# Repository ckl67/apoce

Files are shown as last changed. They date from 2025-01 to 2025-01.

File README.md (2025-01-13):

/* =================================================================
	Pilote Arduino pour optimiser la gestion de consommation électrique
    Christian Klugesherz
    Date : 12 janvier 2025 --> Nouvelle approche avec double fonction de boutons
	
    Le schéma de la carte se trouve dans le répertoire Board
    La simulation se trouve sur
    https://www.tinkercad.com/things/i7El4JjrINq-pilote-contacteur
    L'Arduino Nano est basée sur l'ATmega328

    Code sous github : https://github.com/ckl67/apoce

	ATTENTION:
	===========
		Il est impératif de configurer la partie "Configuration" ci-dessous !
		
    Principe
    =========
    Entrée :
      * Signal Jour/Nuit - J/N
      * Signal Soleil - SOL
    Sortie :
      * Signal pour piloter contacteur Chauffe Eau 1 - CA1
      * Signal pour piloter contacteur Chauffe Eau 2 - CA2
      * Signal pour piloter contacteur Chargement Voiture - CV
	Bouton :
	  * BoutonJN --> Permet aussi de forcer CA1
	  * BoutonSOL--> Permet aussi de forcer CA2
	  * BoutonAUTO--> Permet aussi de forcer V
    Modes :
	  Dans le principe, un changement de mode, va re-initialiser le compteur d'armement

Les Modes disponibles :

	  -------------------------------------------
      * Mode JN : Jour-Nuit --> Led : Bleue Allumée
      --------------------------------------------
	 Si ModeArm = 0
        Si signal J/N = 1
            Basculement entre pilotage "CA1" puis "CA2" 
	 Si ModeArm = 1 
        Si signal J/N = 1
            Basculement entre pilotage "CA1" puis "CA2" puis "CV"  
		
    Si signal J/N = 0
          Pas de pilotage
		  
      -------------------------------------------
      * Mode SOL : Soleil --> Led Orange Allumée
      --------------------------------------------
    Si ModeArm = 0
        Si signal SOL = 1
          Basculement entre pilotage "CA1" puis "CA2"
	  Si ModeArm = 1 
        Si signal SOL = 1
          Basculement entre pilotage "CA1" puis "CA2" puis "CV"
    Si SOL = 0
          Pas de pilotage

      -------------------------------------------
      * Mode Auto : Jour-Nuit + Soleil --> Led Rouge Allumée
      --------------------------------------------
 	 Si ModeArm = 0
        Si signal SOL = 1 || Signal J/N = 1
          Basculement entre pilotage "CA1" puis "CA2"
	Si ModeArm = 1 
        Si signal SOL = 1 || Signal J/N = 1
          Basculement entre pilotage "CA1" puis "CA2" puis "CV"

	Si signal J/N = 0 ET SOL = 0
          Pas de pilotage
	
      -------------------------------------------
      * Bouton Armement pressé 1X --> Led Blanche Clignotante
      --------------------------------------------
		Quelque soit le mode : ModeArm = 1
			--> Nous intégrons la voiture dans le cycle 
			--> Nous utilisons la variable : SwitchContactSelection
			définie : ArmDuration
 
      -------------------------------------------
      * Bouton Armement pressé 2X --> Led Blanche Clignotante Rapide
      --------------------------------------------
			Quelque soit le mode : ModeArm = 2
				Sans courant de nuit, ni Soleil  : Basculement entre pilotage "CA1" puis "CA2" puis "V" sur une durée 
					définie : ArmDuration

      -------------------------------------------
      * Bouton Forcage JN=CA1 ou SOL=CA2 ou AUTO=V 
      -------------------------------------------
      Un premier appui sur le bouton va 
        * Positionner le forcage, 
      un deuxième va 
        * Positionner le mode

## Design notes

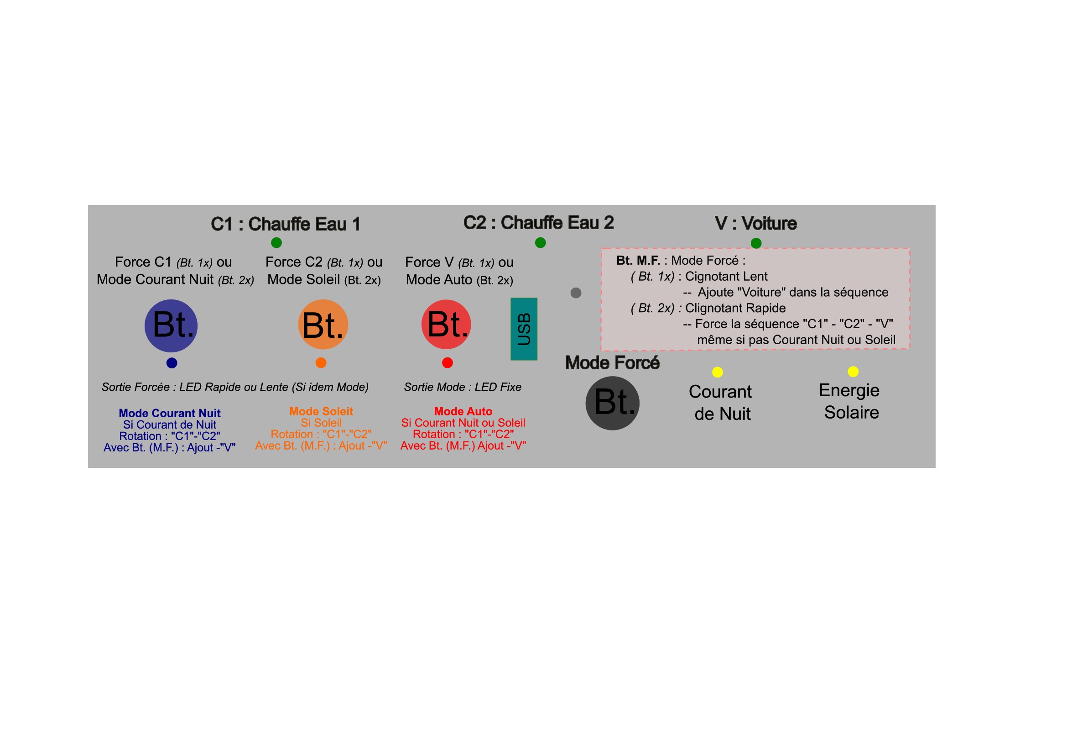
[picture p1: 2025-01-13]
Etiquette/Face.jpg

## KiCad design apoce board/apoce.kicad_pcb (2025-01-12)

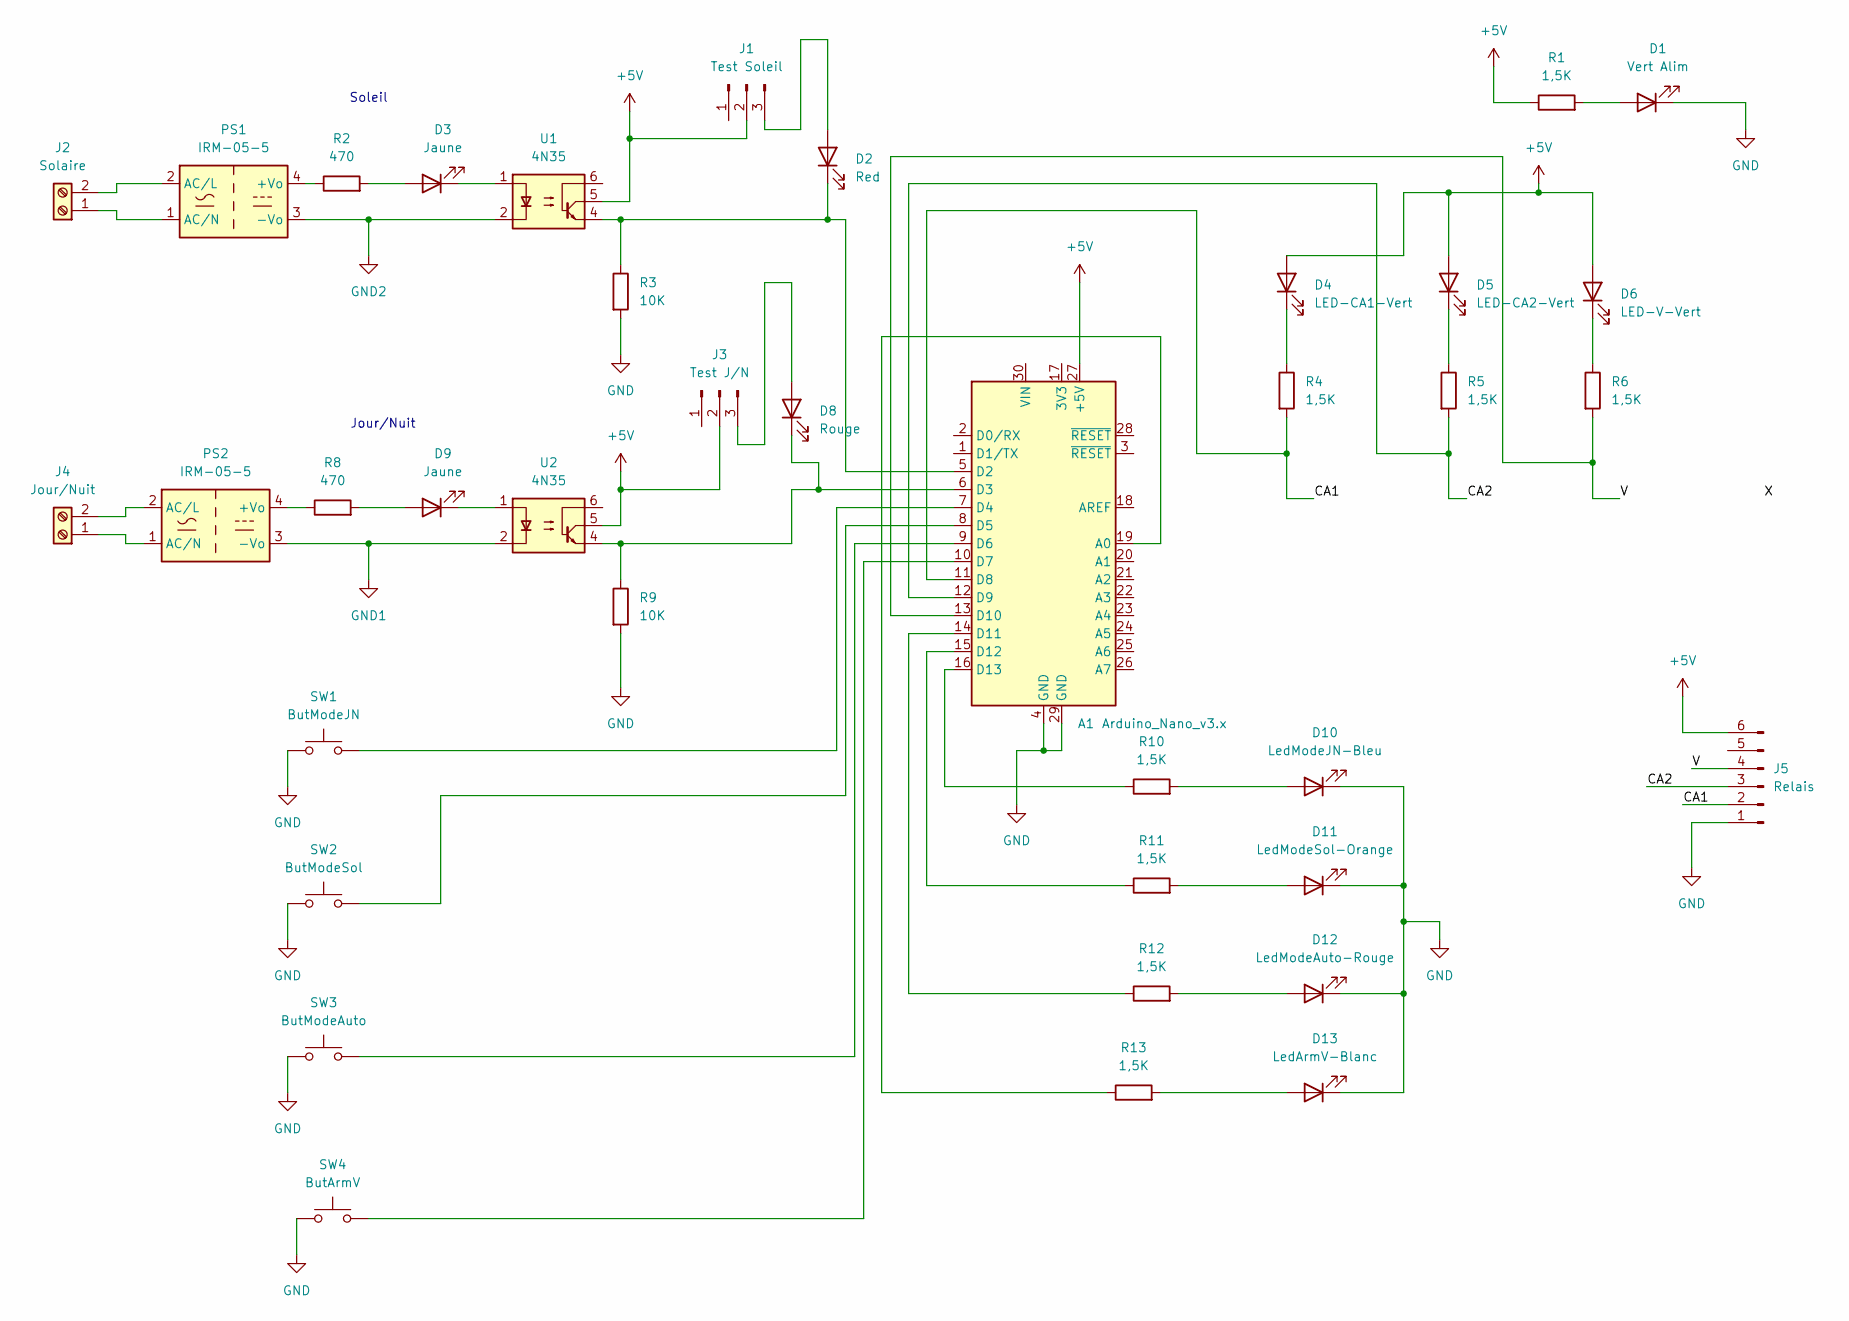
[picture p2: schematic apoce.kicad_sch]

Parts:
A1: Arduino_Nano_v3.x; Arduino_Nano
D1: Vert Alim; LED_D5.0mm
D2: Red; LED_D5.0mm
D3, D9: Jaune; LED_D5.0mm
D4: LED-CA1-Vert; LED_D5.0mm
D5: LED-CA2-Vert; LED_D5.0mm
D6: LED-V-Vert; LED_D5.0mm
D8: Rouge; LED_D5.0mm
D10: LedModeJN-Bleu; LED_D5.0mm
D11: LedModeSol-Orange; LED_D5.0mm
D12: LedModeAuto-Rouge; LED_D5.0mm
D13: LedArmV-Blanc; LED_D5.0mm
J1: Test Soleil; TerminalBlock_Xinya_XY308-2.54-3P_1x03_P2.54mm_Horizontal
J2: Solaire; TerminalBlock_Phoenix_MKDS-1,5-2-5.08_1x02_P5.08mm_Horizont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
J3: Test J/N; TerminalBlock_Xinya_XY308-2.54-3P_1x03_P2.54mm_Horizontal
J4: Jour/Nuit; TerminalBlock_bornier-2_P5.08mm
J5: Relais; TerminalBlock_Xinya_XY308-2.54-6P_1x06_P2.54mm_Horizontal
PS1, PS2: IRM-05-5; Converter_ACDC_MeanWell_IRM-05-xx_THT
R1, R4, R5, R6, R10, R11, R12, R13: 1,5K; R_Axial_DIN0207_L6.3mm_D2.5mm_P10.16mm_Horizontal
R2, R8: 470; R_Axial_DIN0207_L6.3mm_D2.5mm_P10.16mm_Horizontal
R3, R9: 10K; R_Axial_DIN0207_L6.3mm_D2.5mm_P10.16mm_Horizontal
SW1: ButModeJN; TerminalBlock_Phoenix_MKDS-1,5-2-5.08_1x02_P5.08mm_Horizont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
SW2: ButModeSol; TerminalBlock_Phoenix_MKDS-1,5-2-5.08_1x02_P5.08mm_Horizont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
SW3: ButModeAuto; TerminalBlock_Phoenix_MKDS-1,5-2-5.08_1x02_P5.08mm_Horizont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
SW4: ButArmV; TerminalBlock_Phoenix_MKDS-1,5-2-5.08_1x02_P5.08mm_Horizont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
U1, U2: 4N35; DIP-6_W7.62mm_LongPads

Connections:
+5V: A1.27 (+5V), D4.2 (A), D5.2 (A), D6.2 (A), J1.2, J3.2, J5.6, R1.1, U1.5, U2.5
/CA1: A1.11 (D8), J5.2, R4.2
/CA2: A1.12 (D9), J5.3, R5.2
/V: A1.13 (D10), J5.4, R6.2
GND: A1.4 (GND), A1.29 (GND), D1.1 (K), D10.1 (K), D11.1 (K), D12.1 (K), D13.1 (K), J5.1, R3.2, R9.2, SW1.1, SW2.1, SW3.1, SW4.1
GND1: PS2.3 (-Vo), U2.2
GND2: PS1.3 (-Vo), U1.2
unnamed: A1.19 (A0), R13.1
unnamed: A1.5 (D2), D2.1 (K), R3.1, U1.4
unnamed: A1.6 (D3), D8.1 (K), R9.1, U2.4
unnamed: A1.7 (D4), SW1.2
unnamed: A1.8 (D5), SW2.2
unnamed: A1.9 (D6), SW3.2
unnamed: A1.10 (D7), SW4.2
unnamed: A1.14 (D11), R12.1
unnamed: A1.15 (D12), R11.1
unnamed: A1.16 (D13), R10.1
unnamed: D1.2 (A), R1.2
unnamed: D2.2 (A), J1.3
unnamed: D3.2 (A), R2.2
unnamed: D3.1 (K), U1.1
unnamed: D4.1 (K), R4.1
unnamed: D5.1 (K), R5.1
unnamed: D6.1 (K), R6.1
unnamed: D8.2 (A), J3.3
unnamed: D9.2 (A), R8.2
unnamed: D9.1 (K), U2.1
unnamed: D10.2 (A), R10.2
unnamed: D11.2 (A), R11.2
unnamed: D12.2 (A), R12.2
unnamed: D13.2 (A), R13.2
unnamed: J2.1, PS1.1 (AC/N)
unnamed: J2.2, PS1.2 (AC/L)
unnamed: J4.1, PS2.1 (AC/N)
unnamed: J4.2, PS2.2 (AC/L)
unnamed: PS1.4 (+Vo), R2.1
unnamed: PS2.4 (+Vo), R8.1

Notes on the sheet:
Jour/Nuit
Soleil

Board: 2 copper layers, 38 parts (0 on the bottom side), 37 nets, no tracks yet.

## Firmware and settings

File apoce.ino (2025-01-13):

/* =================================================================
	Pilote Arduino pour optimiser la gestion de consommation électrique
    Christian Klugesherz
    Date : 12 janvier 2025 --> Nouvelle approche avec double fonction de boutons
	
    Le schéma de la carte se trouve dans le répertoire Board
    La simulation se trouve sur
    https://www.tinkercad.com/things/i7El4JjrINq-pilote-contacteur
    L'Arduino Nano est basée sur l'ATmega328

    Code sous github : https://github.com/ckl67/apoce

	ATTENTION:
	===========
		Il est impératif de configurer la partie "Configuration" ci-dessous !
		
    Principe
    =========
    Entrée :
      * Signal Jour/Nuit - J/N
      * Signal Soleil - SOL
    Sortie :
      * Signal pour piloter contacteur Chauffe Eau 1 - CA1
      * Signal pour piloter contacteur Chauffe Eau 2 - CA2
      * Signal pour piloter contacteur Chargement Voiture - CV
	Bouton :
	  * BoutonJN --> Permet aussi de forcer CA1
	  * BoutonSOL--> Permet aussi de forcer CA2
	  * BoutonAUTO--> Permet aussi de forcer V
    Modes :
	  Dans le principe, un changement de mode, va re-initialiser le compteur d'armement

Les Modes disponibles :

	  -------------------------------------------
      * Mode JN : Jour-Nuit --> Led : Bleue Allumée
      --------------------------------------------
	 Si ModeArm = 0
        Si signal J/N = 1
            Basculement entre pilotage "CA1" puis "CA2" 
	 Si ModeArm = 1 
        Si signal J/N = 1
            Basculement entre pilotage "CA1" puis "CA2" puis "CV"  
		
    Si signal J/N = 0
          Pas de pilotage
		  
      -------------------------------------------
      * Mode SOL : Soleil --> Led Orange Allumée
      --------------------------------------------
    Si ModeArm = 0
        Si signal SOL = 1
          Basculement entre pilotage "CA1" puis "CA2"
	  Si ModeArm = 1 
        Si signal SOL = 1
          Basculement entre pilotage "CA1" puis "CA2" puis "CV"
    Si SOL = 0
          Pas de pilotage

      -------------------------------------------
      * Mode Auto : Jour-Nuit + Soleil --> Led Rouge Allumée
      --------------------------------------------
 	 Si ModeArm = 0
        Si signal SOL = 1 || Signal J/N = 1
          Basculement entre pilotage "CA1" puis "CA2"
	Si ModeArm = 1 
        Si signal SOL = 1 || Signal J/N = 1
          Basculement entre pilotage "CA1" puis "CA2" puis "CV"

	Si signal J/N = 0 ET SOL = 0
          Pas de pilotage
	
      -------------------------------------------
      * Bouton Armement pressé 1X --> Led Blanche Clignotante
      --------------------------------------------
		Quelque soit le mode : ModeArm = 1
			--> Nous intégrons la voiture dans le cycle 
			--> Nous utilisons la variable : SwitchContactSelection
			définie : ArmDuration
 
      -------------------------------------------
      * Bouton Armement pressé 2X --> Led Blanche Clignotante Rapide
      --------------------------------------------
			Quelque soit le mode : ModeArm = 2
				Sans courant de nuit, ni Soleil  : Basculement entre pilotage "CA1" puis "CA2" puis "V" sur une durée 
					définie : ArmDuration

      -------------------------------------------
      * Bouton Forcage JN=CA1 ou SOL=CA2 ou AUTO=V 
      -------------------------------------------
      Un premier appui sur le bouton va 
        * Positionner le forcage, 
      un deuxième va 
        * Positionner le mode 


 ================================================================== */
// ===== PROTOTYPES ======

void ActiveRelay(int);    // Active le relais
void DeActiveRelay(int);  // Desactive le Relais

void ActiveRelayCA1();
void ActiveRelayCA2();
void ActiveRelayV();

void DeActiveRelayCA1();
void DeActiveRelayCA2();
void DeActiveRelayV();

void WorkMode_JN();    // Mode Nuit en même temps
void WorkMode_SOL();   // Mode Soleil : Uniquement Chauffe Eau rotatif
void WorkMode_Auto();  // Mode Auto, qui après n heures sur m jours va passer k jours en mode JNR

// ===== DEFINE ======

// Carte ou Simulation
#define BoardTinkercad 0
#define BoardHardware 1

// Broches Entrées
// Les entrées sont protégée à travers un Optocoupleur
// Nous mettons également une résistance Pull-Down
// voir commentaire ci-sessous
#define InCurrentSOL 2  // Entrée Lecture Consigne Puissance Soleil atteint
#define InCurrentJN 3   // Entrée Lecture courant de Nuit

// Les boutons sont en Pull UP
// https://www.electrosoftcloud.com/en/arduino-pull-up-pull-down-resistors/
// Une résistance interne de 20kΩ est connectée au 5v interne Arduino
// Le bouton poussoir, qui vient après la résistance, est connecté sur l'entrée Arduino, et est relié par l'autre côté à la masse
//   * appui      --> va ramener la tension à l'entrée à la masse
//   * non appuié --> va maintenir la tension à 5V
// Grâce à cela, nous n'avons plus besoin de résistance pull-up externe que nous pourrons économiser sur notre circuit.
// Cette technique est utilisée en priorité pour éviter une entrée laissée en l’air qui peut avoir n’importe quelle valeur comprise entre 0 et 5 V
// https://www.locoduino.org/spip.php?article122
// https://forum.arduino.cc/t/opto-4n35-on-arduino-digital-input-no-signal/93625
// --> Etat haut inversé

#define ButModeJN 4    // Bouton Mode Jour Nuit
#define ButModeSOL 5   // Bouton Mode Soleil
#define ButModeAUTO 6  // Bouton Mode Auto
#define ButArm 7       // Bouton Armement

// Broches Sorties
#define LedArm A0  // Led Armement (Une Entrée/Sortie Analogique peut être utilisée en Digitale)

#define LedModeAUTO 11  // Led pour choix mode Auto
#define LedModeSOL 12   // Led pour choix Mode Soleil
#define LedModeJN 13    // Led pour choix Mode Jour/Nuit

#define OutCA1 8  // Sortie pour piloter contacteur Chauffe Eau 1
#define OutCA2 9  // Sortie pour piloter contacteur Chauffe Eau 2
#define OutV 10   // Sortie pour piloter contacteur Voiture

// Modes de fonctionnement
#define ModeJN 1    // Mode Jour-Nuit
#define ModeSOL 2   // Mode Soleil
#define ModeAUTO 3  // Mode Auto

// Position Bit pour le mode Forcer
// 	JN=CA1	SOL=CA2	AUTO=V Résultat=ValForceMode selon position de bits
#define BitForceCA1 2  // Bit Force Mode CA1
#define BitForceCA2 1  // Bit Force Mode CA2
#define BitForceV 0    // Bit Force Mode Voiture

// Modes d'Armement
#define ModeNoARM 0      // Pas de mode Armement
#define ModeARMSimple 1  // Mode Armement Simple
#define ModeARMDouble 2  // Mode Aremement Double

// ****************************************************
// ****************************************************
//                  DEBUT - CONFIGURATIONS
// ****************************************************
// ****************************************************
// Type de Carte : Simulation TinkerPad ou Carte Réelle
//    Choix entre : BoardTinkercad / BoardHardware
//    --> La différence tient en l'activation des sorties relais qui se font en
//    * Signal haut pour la Simulation BoardTinkercad
//    * Signal bas pour la carte BoardHardware
#define BoardType BoardHardware

// MODE Debug  avec Sortie Série : true ou false
#define Debug_Mode_Serie false

// ----------------------------------------------------
//                   FIN - CONFIGURATIONS
// ----------------------------------------------------

// Interval de clignottement LED
//   Valeur multiplicateur en (s)
#define LedIntervalSlow 1000ul * 1
#define LedIntervalFast 1000ul / 2

// Durée Armement Mode forcé
//   Valeur multiplicateur en (s)
#define ArmDuration_Real 1000ul * (3600 * 12)
#define ArmDuration_Simul 1000ul * (20)

// Interval de basculement entre les contacteurs
//   Valeur multiplicateur en (s)
//   En référence aux 8 heures de courant de nuit
//   --> 30 minutes entre basculement (60 * 30)
#define SwitchContactInterval_Real 1000ul * (60 * 30)
#define SwitchContactInterval_Simul 1000ul * (3)

// ======================================= VARIABLES  ===============================

// Variable Buttons
boolean ButModeJNwasUp;
boolean ButModeSOLwasUp;
boolean ButModeAUTOwasUp;
boolean ButArmwasUp;

// Variable Bouton : Vérifie si un bouton est pressé 2 fois
boolean ButSecondPushJN;
boolean ButSecondPushSOL;
boolean ButSecondPushAUTO;
boolean ButArmSecondPush;

// Temps
unsigned long CurrentMillis;

// Tempos
unsigned long val_ArmDuration;
unsigned long val_SwitchContactInterval;

// Variable "temps" pour contôler clignottement de toutes les LEDs
unsigned long LedPreviousMillis;
unsigned long LedFastPreviousMillis;
unsigned long LedArmPreviousMillis;

// Variable clignottement Led
int LedInterval;
int LedFastInterval;
int LedArmInterval;

// Variable temps pour contrôler les contacteurs
unsigned long SwitchContactPreviousMillis;

// Variable de rotation pour balayer les contacteurs
//    0=CA1 , 1=CA2 , 2=Voiture
int SwitchContactSelection;

// Variable temps pour contrôler bouton armement
unsigned long ArmPreviousMillis;

// Etat Clignottement des LEDs
int LedBlinkingState;      // LOW ou HIGH, Valeur de Clignottement de la Led
int LedFastBlinkingState;  // LOW ou HIGH, Valeur de Clignottement de la Led

// Etat LED pour aArmement
int LedArmBlinkingState;  // LOW ou HIGH, Valeur de Clignottement de la Led

// Etat de L'armement.
boolean ArmTriggerStatus;
boolean ArmDoubleTriggerStatus;

// Variable Mode de fonctionnement
int Mode;
int ModeArm;

// Varibale qui détermine le mode Forcé
// 	JN=CA1	SOL=CA2	AUTO=V Résultat=ValForceMode selon position de bits

uint8_t ValForceMode;

// ======================================= SETUP ===============================
void setup() {

  if (Debug_Mode_Serie)
    Serial.begin(9600);

  pinMode(InCurrentSOL, INPUT);
  pinMode(InCurrentJN, INPUT);

  pinMode(ButModeJN, INPUT_PULLUP);
  pinMode(ButModeAUTO, INPUT_PULLUP);
  pinMode(ButModeSOL, INPUT_PULLUP);
  pinMode(ButArm, INPUT_PULLUP);

  pinMode(LedModeSOL, OUTPUT);
  pinMode(LedModeAUTO, OUTPUT);
  pinMode(LedModeJN, OUTPUT);
  pinMode(LedArm, OUTPUT);

  pinMode(OutCA1, OUTPUT);
  pinMode(OutCA2, OUTPUT);
  pinMode(OutV, OUTPUT);

  digitalWrite(LedModeJN, LOW);
  digitalWrite(LedModeSOL, LOW);
  digitalWrite(LedModeAUTO, LOW);
  digitalWrite(LedArm, LOW);

  // Variable Button
  ButModeJNwasUp = true;
  ButModeAUTOwasUp = true;
  ButModeSOLwasUp = true;
  ButArmwasUp = true;

  ButSecondPushJN = false;
  ButSecondPushSOL = false;
  ButSecondPushAUTO = false;
  ButArmSecondPush = false;

  // Temps
  CurrentMillis = 0;

  // Tempos
  if (BoardType == BoardTinkercad) {
    val_ArmDuration = ArmDuration_Simul;
    val_SwitchContactInterval = SwitchContactInterval_Simul;
  } else {
    val_ArmDuration = ArmDuration_Real;
    val_SwitchContactInterval = SwitchContactInterval_Real;
  }

  // Variable "temps" pour contôler clignottement de toutes les LEDs
  LedPreviousMillis = CurrentMillis;
  LedFastPreviousMillis = CurrentMillis;
  LedArmPreviousMillis = CurrentMillis;

  // Variable clignottement Led
  LedInterval = LedIntervalSlow;
  LedFastInterval = LedIntervalFast;
  LedArmInterval = LedIntervalSlow;

  // Variable temps pour contrôler les contacteurs
  SwitchContactPreviousMillis = CurrentMillis;

  // Variable de rotation pour balayer les contacteurs
  //    0=CA1 , 1=CA2 , 2=Voiture
  SwitchContactSelection = 0;

  // Tempo d'armement
  // Variable temps pour contrôler bouton armement
  ArmPreviousMillis = CurrentMillis;

  // Variable pour led clignottement en fonctionnement Forcé
  LedBlinkingState = LOW;
  LedFastBlinkingState = LOW;
  LedArmBlinkingState = LOW;

  // Etat de L'armement.
  ArmTriggerStatus = false;
  ArmDoubleTriggerStatus = false;

  // Variable Mode de fonctionnement
  Mode = ModeAUTO;
  ModeArm = ModeNoARM;

  // Varibale qui détermine le mode Forcé
  // 	JN=CA1	SOL=CA2	AUTO=V Résultat=ValForceMode selon position de bits
  ValForceMode = 0;

  DeActiveRelayCA1();
  DeActiveRelayCA2();
  DeActiveRelayV();

}

// ======================== LOOP ====================================
// On va tourner sans arrêt dans cette boucle
// ==================================================================
void loop() {

  // Varibales locales
  boolean ButModeJNisUp;
  boolean ButModeSOLisUp;
  boolean ButModeAUTOisUp;
  boolean ButArmisUp;

  // ----------------------------------------------------------------
  // --- PREMIERE TACHE DANS LA BOUCLE INFINIE : CONTROLE DES LEDs
  // ----------------------------------------------------------------
  // Il n'y a pas de problème à utiliser millis() pendant plusieurs années,
  // si on utilise toujours la formule qui compare la différence de 2 temps à un seuil.
  CurrentMillis = millis();

  // ----------- Compteur de Clignotement Rapide Led  ---------------------
  if (CurrentMillis - LedFastPreviousMillis >= LedIntervalFast) {
    LedFastPreviousMillis = CurrentMillis;

    // if the LED is off turn it on
    if (LedFastBlinkingState == LOW) {
      LedFastBlinkingState = HIGH;
    } else {
      LedFastBlinkingState = LOW;
    }
  }

  // ----------- Compteur de Clignotement Led  ---------------------
  if (CurrentMillis - LedPreviousMillis >= LedInterval) {
    LedPreviousMillis = CurrentMillis;

    // if the LED is off turn it on
    if (LedBlinkingState == LOW) {
      LedBlinkingState = HIGH;
    } else {
      LedBlinkingState = LOW;
    }
  }

  // ----------- Compteur de Clignotement Led Armement---------------------
  if (CurrentMillis - LedArmPreviousMillis >= LedArmInterval) {
    LedArmPreviousMillis = CurrentMillis;

    // if the LED is off turn it on and vice-versa:
    if (LedArmBlinkingState == LOW) {
      LedArmBlinkingState = HIGH;
    } else {
      LedArmBlinkingState = LOW;
    }
    // Durée clignottement
    if (ModeArm == ModeARMDouble)
      LedArmInterval = LedIntervalFast;
    else
      LedArmInterval = LedIntervalSlow;
  }

  // ----- Compteur Armement : Fin du compteur  ---------------------
  if (CurrentMillis - ArmPreviousMillis >= val_ArmDuration) {
    ArmPreviousMillis = CurrentMillis;

    // A la fin de la tempo, un second appui ne doit pas faire changer de mode !!
    ButSecondPushJN = false;
    ButSecondPushSOL = false;
    ButSecondPushAUTO = false;

    ValForceMode = 0;

    ModeArm = ModeNoARM;
    ButArmSecondPush = false;
  }

  // ----- Compteur Switch entre CA1, CA2 et Voiture ---------------------
  if (CurrentMillis - SwitchContactPreviousMillis >= val_SwitchContactInterval) {
    SwitchContactPreviousMillis = CurrentMillis;
    SwitchContactSelection = SwitchContactSelection + 1;

    if (ModeArm == ModeNoARM) {
      if (SwitchContactSelection > 1)
        SwitchContactSelection = 0;
    } else {
      if (SwitchContactSelection > 2)
        SwitchContactSelection = 0;
    }
  }

  // ----------------------------------------------------------------
  // --- DEUXIEME TACHE DANS LA BOUCLE INFINIE : LECTURE DES BOUTONS
  // ----------------------------------------------------------------
  //    Attention nous sommes en mode PULLUP --> valeur actif = 0 !
  //    Le mode INPUT_PULLUP est disponible sur les broches de l'Arduino.
  //    Une résistance interne de 20kΩ est connectée au 5v interne Arduino
  //    Le bouton poussoir, qui vient après la résistance, est connecté sur l'entrée Arduino, et est relié par l'autre côté à la masse
  //        * appui      --> va ramener la tension à l'entrée à la masse
  //        * non appuié --> va maintenir la tension à 5V
  //    Grâce à cela, nous n'avons plus besoin de résistance pull-up externe que nous pourrons économiser sur notre circuit.

  ButModeJNisUp = digitalRead(ButModeJN);
  ButModeSOLisUp = digitalRead(ButModeSOL);
  ButModeAUTOisUp = digitalRead(ButModeAUTO);
  ButArmisUp = digitalRead(ButArm);

  // --------------------------
  // si bouton Mode JN pressé
  // --------------------------
  if (ButModeJNwasUp && !ButModeJNisUp) {
    delay(10);
    ButModeJNisUp = digitalRead(ButModeJN);
    if (!ButModeJNisUp) {

      if (ButSecondPushJN == false) {
        // Active le mode forcé pour une sortie
        ButSecondPushJN = true;
        ValForceMode = ValForceMode | (1 << BitForceCA1);

        // On remet l'armement à zéro dans l'Activation du mode Forcé
        ArmPreviousMillis = CurrentMillis;

      } else {
        // On confirme le mode ModeJN
        Mode = ModeJN;

        ButSecondPushJN = false;
        ButSecondPushSOL = false;
        ButSecondPushAUTO = false;
        ButArmSecondPush = false;

        // Désacive le mode forcé
        ValForceMode = 0;

        ModeArm = ModeNoARM;
        ArmTriggerStatus = false;
        ArmDoubleTriggerStatus = false;

        SwitchContactSelection = 0;
      }
    }

    delay(10);
  }
  ButModeJNwasUp = ButModeJNisUp;  // true = bouton relaché  --> mémorise l'état

  // --------------------------
  // si bouton Mode Soleil pressé
  // --------------------------
  if (ButModeSOLwasUp && !ButModeSOLisUp) {
    delay(10);
    ButModeSOLisUp = digitalRead(ButModeSOL);

    if (!ButModeSOLisUp) {

      if (ButSecondPushSOL == false) {
        // Active le mode forcé pour une sortie
        ButSecondPushSOL = true;
        ValForceMode = ValForceMode | (1 << BitForceCA2);

        // On remet l'armement à zéro dans l'Activation du mode Forcé
        ArmPreviousMillis = CurrentMillis;

      } else {
        // On confirme le mode ModeSOL
        Mode = ModeSOL;

        ButSecondPushJN = false;
        ButSecondPushSOL = false;
        ButSecondPushAUTO = false;
        ButArmSecondPush = false;

        // Désacive le mode forcé
        ValForceMode = 0;

        ModeArm = ModeNoARM;
        ArmTriggerStatus = false;
        ArmDoubleTriggerStatus = false;

        SwitchContactSelection = 0;
      }
    }

    delay(10);
  }
  ButModeSOLwasUp = ButModeSOLisUp;  // = true bouton relaché  --> mémorise l'état

  // --------------------------
  // si bouton Mode Auto pressé
  // --------------------------
  if (ButModeAUTOwasUp && !ButModeAUTOisUp) {
    delay(10);
    ButModeAUTOisUp = digitalRead(ButModeAUTO);
    if (!ButModeAUTOisUp) {


      if (ButSecondPushAUTO == false) {
        // Active le mode forcé pour une sortie
        ButSecondPushAUTO = true;
        ValForceMode = ValForceMode | (1 << BitForceV);

        // On remet l'armement à zéro dans l'Activation du mode Forcé
        ArmPreviousMillis = CurrentMillis;

      } else {
        // Active le mode forcé pour une sortie
        Mode = ModeAUTO;

        ButSecondPushJN = false;
        ButSecondPushSOL = false;
        ButSecondPushAUTO = false;
        ButArmSecondPush = false;

        // Désacive le mode forcé
        ValForceMode = 0;

        ModeArm = ModeNoARM;
        ArmTriggerStatus = false;
        ArmDoubleTriggerStatus = false;

        SwitchContactSelection = 0;
      }
    }

    delay(10);
  }
  ButModeAUTOwasUp = ButModeAUTOisUp;  // = true bouton relaché  --> mémorise l'état

  // --------------------------
  // si Bouton ARM pressé
  // --------------------------
  if (ButArmwasUp && !ButArmisUp) {
    delay(10);
    ButArmisUp = digitalRead(ButArm);

    if (!ButArmisUp) {

      if (ButArmSecondPush == false) {
        ModeArm = ModeARMSimple;
        ButArmSecondPush = true;
      } else {
        ModeArm = ModeARMDouble;
        ButArmSecondPush = false;
      }
    }
    // Init Variables
    // On remet l'armement à zéro
    ArmPreviousMillis = CurrentMillis;
  }
  ButArmwasUp = ButArmisUp;  // true = bouton relaché  --> mémorise l'état

  // ----------------------------------------------------------------
  // --- TROISIEME TACHE DANS LA BOUCLE INFINIE : ON ACTIVE lES SORTIES
  // ----------------------------------------------------------------
  switch (Mode) {
    case ModeJN:
      WorkMode_JN();
      break;

    case ModeSOL:
      WorkMode_SOL();
      break;

    case ModeAUTO:
      WorkMode_Auto();
      break;

    default:
      WorkMode_Auto();
      break;
  }

  // ----------------------------------------------------------------
  // --- QUATRIEME TACHE DANS LA BOUCLE INFINIE :
  //      ON ENVOIE si nécessaire les sorties en DEBUG
  // ----------------------------------------------------------------

  if (Debug_Mode_Serie) {
    Serial.print("Md=");
    Serial.print(Mode);
    Serial.write("   ");

    Serial.print("Ma=");
    Serial.print(ModeArm);
    Serial.write("   ");

    Serial.print("VF=");
    Serial.print(ValForceMode);
    Serial.write("   ");

    Serial.println();
  }

  // Délai
  delay(100);
}

// ========================================= FIN LOOP ====================================

// ===================================================================================================
// ========================================= PROCEDURES ==============================================
// ===================================================================================================

void ActiveRelayCA1() {
  ActiveRelay(OutCA1);
}

void ActiveRelayCA2() {
  ActiveRelay(OutCA2);
}

void ActiveRelayV() {
  ActiveRelay(OutV);
}

// -----------------------------

void DeActiveRelayCA1() {
  if (((ValForceMode >> BitForceCA1) & 1) == 1) {
    ActiveRelay(OutCA1);
  } else {
    DeActiveRelay(OutCA1);
  }
}

void DeActiveRelayCA2() {
  if (((ValForceMode >> BitForceCA2) & 1) == 1) {
    ActiveRelay(OutCA2);
  } else {
    DeActiveRelay(OutCA2);
  }
}

void DeActiveRelayV() {
  if (((ValForceMode >> BitForceV) & 1) == 1) {
    ActiveRelay(OutV);
  } else {
    DeActiveRelay(OutV);
  }
}

// -------------------------------------------------------------------------------------------
// -------------------------------------------------------------------------------------------

void ActiveRelay(int pin) {
  if (BoardType == BoardHardware) {
    // Resitance Pull Up
    digitalWrite(pin, LOW);
  } else {
    digitalWrite(pin, HIGH);
  }
}

// -------------------------------------------------------------------------------------------
// -------------------------------------------------------------------------------------------
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

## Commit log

2024-06-03 Ajout méthode de permutation de la valeur de tempo à travers l'appui des 3 boutons
2024-06-03 Petite correction pour permettre la gestion des 3 boutons
    [apoce.ino]
2024-06-03 Correction Bug 3 boutons
    [apoce.ino]
2024-08-15 Ajout Carte
    [apoce.kicad_pcb, apoce.kicad_sch]
2024-08-15 Etape 1 pour le placement routage
    [apoce.kicad_pcb, apoce.kicad_sch]
2025-01-05 Nouvelle version avec amélioration
    [apoce.kicad_sch]
2025-01-08 Revert "Nouvelle version avec amélioration"
    This reverts commit 7894d477df82a93182f71be82a563ec3e50d3505.
    [apoce.kicad_sch]
2025-01-08 Reapply "Nouvelle version avec amélioration"
    This reverts commit de40c29c87853ffb3fdf9fb958bdbe0331c75c98.
    [apoce.kicad_sch]
2025-01-12 Préparation à travers une logique de controle
    #define BitForceCA1 0x3 // Force Mode CA1
    #define BitForceCA2 0x2 // Force Mode CA2
    #define BitForceV 0x1 // Force Mode Voiture
2025-01-12 On a séparer les compteurs Led de forcage
    [apoce.kicad_pcb, apoce.kicad_sch]
